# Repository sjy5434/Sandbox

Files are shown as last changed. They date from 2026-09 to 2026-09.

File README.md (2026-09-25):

# Koi Fish Joint Test Piece

A small OpenSCAD test print for an articulating koi fish: two tapered body
segments joined by a print-in-place ball-and-socket joint, with a separate
raised scale layer for dual-color printing on the AMS.

## Files

- `koi_joint_test.scad` — the parametric model.
- `export/joint_test_body.stl` — base body (both segments + joint), color 1.
- `export/joint_test_scales.stl` — raised scale layer, color 2.
- `export/koi_joint_test.3mf` — combined preview export only; confirmed
  single-object, see note below.

## Use the two STLs, not the 3MF

Confirmed in this environment: OpenSCAD 2021.01's built-in 3MF exporter
flattens the whole design into a **single mesh/object** (verified by
inspecting the exported `3D/3dmodel.model` XML — it contains exactly one
`<object>` element covering both the body and the scales). It does not
preserve them as separate objects the way Bambu Studio needs in order to
expose two independently paintable parts, so `koi_joint_test.3mf` is only
useful as a quick single-color preview, not for AMS slot assignment.

Use the two STL files instead — that's the reliable workflow:

1. In Bambu Studio, **Import** both `joint_test_body.stl` and
   `joint_test_scales.stl` into the same project.
2. They will already be aligned (both were exported from the same
   coordinate system in the .scad file — don't move one without the other).
3. Right-click each part → assign it to a different AMS filament slot
   (e.g. body → slot 1, scales → slot 2).
4. Group/arrange as needed, but keep their relative position fixed so the
   scale layer still sits flush on the body surface.

If you'd rather have a single file, Bambu Studio can merge the two STLs into
one project and re-export as a `.3mf` itself — that project-level 3MF *does*
preserve the two objects/paint assignments, unlike OpenSCAD's exporter.

## Print orientation

**Print it exactly as modeled — joint axis vertical (Z), no rotation in the
slicer.** The socket cavity opens upward by design:

- Segment B (bottom) tapers 18→14 mm and has the ball-cage/socket carved
  into its top.
- The ball (attached to segment A) sits inside that cage with a uniform
  `joint_clearance` (0.3 mm default) gap on all sides.
- Segment A (top) tapers 14→18 mm, connected to the ball by a short neck rod
  that passes up through a flared opening in the socket's top.

Because the opening faces up, the ball's equator and upper hemisphere print
as a series of closely-nested rings right next to the matching socket wall,
separated only by the clearance gap. That gap is small enough to bridge
layer-by-layer, so **no internal supports are needed inside the joint
cavity**. Do not lay the part on its side — that reintroduces a real
overhang on the ball and will force supports that fuse into the socket.

No supports are needed anywhere else on the part either (the tapered bodies
and scale bumps are all self-supporting/shallow-angle geometry). Standard
0.2 mm layer height should be fine; if your printer/filament tends to blob
on bridges, consider dropping to 0.16 mm around the joint region only.

## Build volume sanity check

With the default parameters:

- Total height ≈ 25 (segment B) + ~11.6 (joint/neck region) + 25 (segment A)
  ≈ **61.6 mm**
- Max diameter ≈ **18 mm** (the large end of each segment; the joint knuckle
  bulges to ~15.2 mm, still under the segment's max diameter)

That's a footprint on the order of 18 × 18 mm and ~62 mm tall — trivially
within the Bambu Lab A1 mini's 180 × 180 × 180 mm build volume, whether you
print it standing up (as recommended) or need to reorient for some other
reason.

## Judging `joint_clearance` after the test print

Print with the default `joint_clearance = 0.3` mm first, then adjust based
on what you see:

**Too tight (fused / won't move):**
- The joint doesn't rotate at all, or takes visible force and grinds/creaks.
- You see witness marks or torn strands where the ball and socket surfaces
  touched and welded together during printing.
- Twisting it further shows white stress marks or the neck rod flexing
  instead of the ball rotating.
- Fix: increase `joint_clearance` in 0.05–0.1 mm steps (try 0.35, then 0.4)
  and reprint.

**Too loose (sloppy articulation):**
- The ball rattles inside the socket or has noticeable play/wobble beyond
  just rotating.
- You can see daylight/gap around the ball when viewed from the side at the
  equator, well beyond a thin uniform line.
- The joint flops under the segment's own weight instead of holding a pose.
- Fix: decrease `joint_clearance` in 0.05 mm steps (try 0.25, then 0.2) and
  reprint. Very fine-detail printers/filaments (e.g. well-tuned PETG or ABS)
  can often go tighter than PLA before fusing.

**Good result:** the joint rotates smoothly with light, consistent
resistance in every direction, holds a pose against gravity, and shows no
fused/torn surface texture when you look inside the visible neck opening.

Other parameters worth revisiting once clearance is dialed in:
- `opening_extra` / `opening_flare` control how much the ball can swing
  before the neck rod hits the socket's opening wall — widen these if you
  want more range of motion once the base friction is right.
- `scale_size`, `scale_spacing_v`, `scale_spacing_a`, `scale_height` control
  the scale texture density/relief and can be tuned independently of the
  joint.

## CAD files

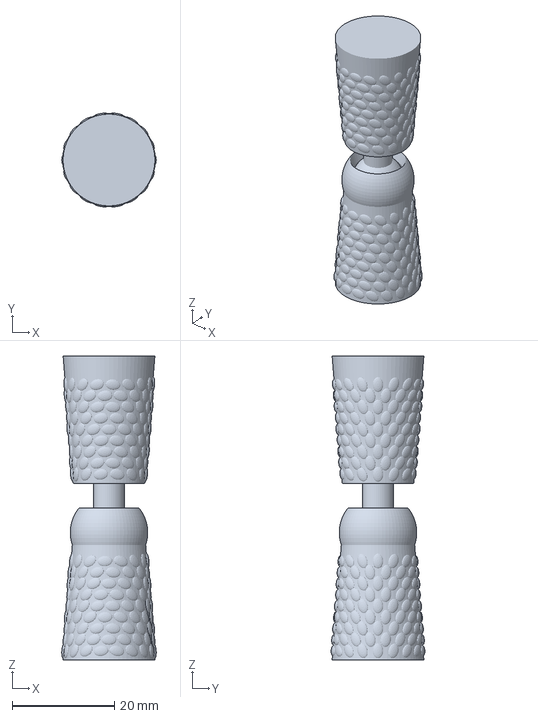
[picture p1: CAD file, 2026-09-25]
export/koi_joint_test.3mf
18.5 x 18.4 x 59.6 mm

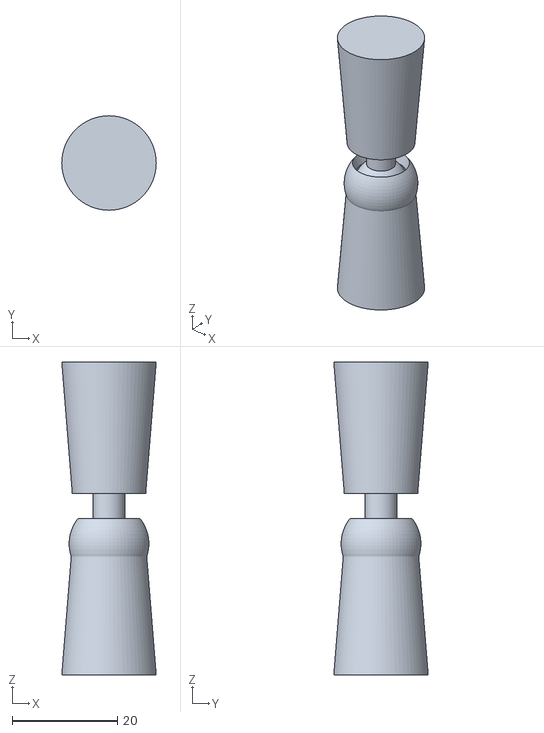
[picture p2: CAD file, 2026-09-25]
export/joint_test_body.stl
18.0 x 18.0 x 59.6

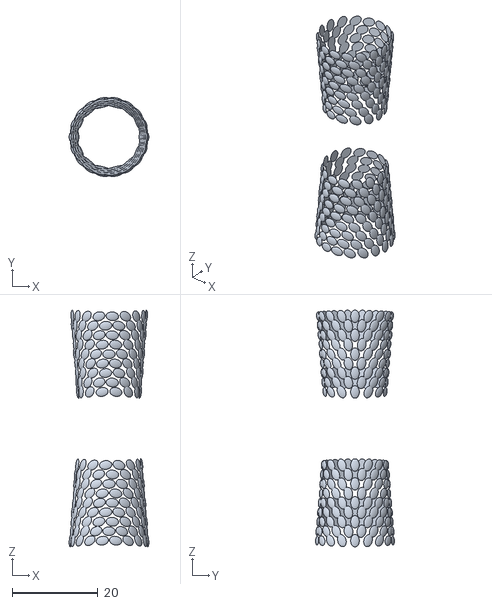
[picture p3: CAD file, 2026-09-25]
export/joint_test_scales.stl
18.5 x 18.4 x 55.1

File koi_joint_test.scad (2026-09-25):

// ============================================================================
// koi_joint_test.scad
//
// Small test piece for an articulating koi fish: two tapered body segments
// joined by a PRINT-IN-PLACE ball-and-socket joint, plus a separate raised
// scale layer for dual-color (AMS) printing.
//
// PRINT ORIENTATION (do not rotate before slicing):
//   The model is built with the joint axis along Z and the socket cavity
//   opening UPWARD (segment B at the bottom, its socket facing +Z; the ball
//   and segment A sit above it). Printing with this orientation as-is is
//   what lets the ball's equator/upper hemisphere print without support:
//   each layer of the ball is closely nested inside a matching ring of the
//   socket wall, separated only by `joint_clearance`, so the gap is bridged
//   layer-by-layer instead of needing an overhang support structure. Do NOT
//   lay the model on its side in the slicer, or the ball will need supports
//   that fuse into the socket cavity.
//
// Two independent top-level solids are emitted (never unioned together):
//   - base_body()   : the printable body (both tapered segments + joint)
//   - scales_layer(): raised scale bumps, sitting exactly on the body's
//                      outer surface, for assigning to a second AMS slot.
//
// Render/export selection is controlled by the `render_part` variable below,
// which can be overridden from the command line with -D, e.g.:
//   openscad -D 'render_part="body"'   -o joint_test_body.stl   koi_joint_test.scad
//   openscad -D 'render_part="scales"' -o joint_test_scales.stl koi_joint_test.scad
// ============================================================================

/* [Articulation - tune these after the first test print] */
joint_clearance = 0.3;   // gap (mm) between ball and socket surfaces
seg_length      = 25;    // length (mm) of each tapered body segment
diam_large      = 18;    // large-end diameter (mm) of each segment
diam_small      = 14;    // small-end (joint-side) diameter (mm) of each segment

/* [Joint geometry - secondary tunables] */
ball_d        = 11;    // ball diameter (mm)
neck_d        = 6;     // diameter (mm) of the rigid rod connecting segment A to the ball
opening_extra = 2.5;   // how much wider than the neck the socket's top opening starts (mm)
opening_flare = 4;     // extra widening (mm) of the opening toward the top, for range of motion
socket_wall   = 1.8;   // wall thickness (mm) of the socket housing around the ball cavity

/* [Scale texture - parametric] */
scale_size      = 3;     // scale footprint length along the body (mm)
scale_width     = 0.7;   // scale width as a fraction of scale_size
scale_height    = 0.4;   // how far scales sit proud of the base body surface (mm)
scale_spacing_v = 2.2;   // vertical spacing between scale rows (mm) - less than scale_size so rows overlap
scale_spacing_a = 3.0;   // approx. arc spacing between scales within a row (mm)

/* [Render control] */
render_part = "both"; // "both" | "body" | "scales"  (override with -D on the command line)

$fn = 64;

// ---------------------------------------------------------------------------
// Derived dimensions
// ---------------------------------------------------------------------------
ball_r    = ball_d / 2;
neck_r    = neck_d / 2;
opening_r = neck_r + joint_clearance + opening_extra / 2;
housing_r = ball_r + joint_clearance + socket_wall;

z_ball      = seg_length;              // height of the ball/socket center (top of segment B's taper)
neck_len    = housing_r + 2;           // neck rod length from ball center to above the housing dome
neck_top_z  = z_ball + neck_len;       // height where segment A's tapered body begins

// ---------------------------------------------------------------------------
// Generic helper: rotate children so their local +Z axis aligns with vector v
// ---------------------------------------------------------------------------
module align_to(v) {
    vn = v / norm(v);
    zaxis = [0, 0, 1];
    d = zaxis * vn;
    if (d > 0.999999) {
        children();
    } else if (d < -0.999999) {
        rotate([180, 0, 0]) children();
    } else {
        ax = cross(zaxis, vn);
        ang = acos(d);
        rotate(a = ang, v = ax) children();
    }
}

// ---------------------------------------------------------------------------
// BASE BODY: segment B (bottom) + socket housing + ball/neck + segment A (top)
// ---------------------------------------------------------------------------
module tapered_body(len, d1, d2) {
    cylinder(h = len, d1 = d1, d2 = d2, $fn = 64);
}

module base_body() {
    union() {
        // Segment B: tapered body with the socket housing carved into its top
        difference() {
            union() {
                tapered_body(seg_length, diam_large, diam_small);
                translate([0, 0, z_ball]) sphere(r = housing_r, $fn = 64);
            }
            // Ball clearance cavity (full sphere so the ball is caged, not just resting in a bowl)
            translate([0, 0, z_ball]) sphere(r = ball_r + joint_clearance, $fn = 64);
            // Upward-facing opening for the neck rod; flares outward near the top for swing range
            translate([0, 0, z_ball])
                cylinder(h = neck_len + 5, r1 = opening_r, r2 = opening_r + opening_flare, $fn = 48);
        }

        // Ball + neck, rigidly part of segment A, sitting inside B's cavity with clearance on all sides
        translate([0, 0, z_ball]) sphere(r = ball_r, $fn = 64);
        translate([0, 0, z_ball]) cylinder(h = neck_len, r = neck_r, $fn = 48);

        // Segment A: tapered body above the neck
        translate([0, 0, neck_top_z]) tapered_body(seg_length, diam_small, diam_large);
    }
}

// ---------------------------------------------------------------------------
// SCALE LAYER: separate solid, raised scale_height above the base body surface
// ---------------------------------------------------------------------------
module scale_bump() {
    // Half-ellipsoid ("half-moon") dome: flat base at z=0 sits exactly on the
    // body's tangent plane at each grid point, dome rises +scale_height above it.
    intersection() {
        scale([scale_size / 2, (scale_size * scale_width) / 2, scale_height])
            sphere(r = 1, $fn = 16);
        translate([-100, -100, 0]) cube([200, 200, 200]);
    }
}

// Places one scale on a cone of local slope m (dr/dz) at azimuth theta and height z_local,
// with the cone's local radius r_local at that height.
module place_bump(theta, z_local, r_local, m) {
    pos = [r_local * cos(theta), r_local * sin(theta), z_local];
    normal = [cos(theta), sin(theta), -m];
    translate(pos) align_to(normal) scale_bump();
}

// Generates a diagonal (staggered) grid of scales over a tapered segment of length `len`
// whose radius goes from r1 (z=0) to r2 (z=len).
module gen_scales(len, r1, r2) {
    m = (r2 - r1) / len;
    margin = scale_size * 0.6;
    usable = len - 2 * margin;
    num_rows = floor(usable / scale_spacing_v);
    for (row = [0 : num_rows - 1]) {
        z = margin + row * scale_spacing_v;
        r_local = r1 + m * z;
        circumference = 2 * PI * r_local;
        num_cols = max(6, floor(circumference / scale_spacing_a));
        theta_step = 360 / num_cols;
        offset = (row % 2 == 0) ? 0 : theta_step / 2;
        for (col = [0 : num_cols - 1]) {
            theta = col * theta_step + offset;
            place_bump(theta, z, r_local, m);
        }
    }
}

module scales_layer() {
    union() {
        // Scales on segment B (bottom, large->small going up)
        gen_scales(seg_length, diam_large / 2, diam_small / 2);
        // Scales on segment A (top, small->large going up) - joint knuckle left bare
        translate([0, 0, neck_top_z]) gen_scales(seg_length, diam_small / 2, diam_large / 2);
    }
}

// ---------------------------------------------------------------------------
// Output selection
// ---------------------------------------------------------------------------
if (render_part == "body") {
    base_body();
} else if (render_part == "scales") {
    scales_layer();
} else {
    base_body();
    color("Orange") scales_layer();
}

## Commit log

2026-09-25 Add koi joint test: print-in-place ball joint with dual-color scales
    Two tapered body segments (25mm, 18->14mm) joined by a captured
    ball-and-socket joint printed with the socket opening facing up so no
    internal supports are needed. joint_clearance, segment length, and
    diameter are top-level parameters for tuning after the first print.
    Scales are modeled as a separate solid raised ~0.4mm above the body
    surface in a diagonal, overlapping grid, so it can be assigned to a
    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
    [joint_test_body.stl, joint_test_scales.stl, koi_joint_test.scad]
2026-09-25 Confirm 3MF export is single-object; document STL workflow
    Inspected the exported 3MF's model XML directly: OpenSCAD 2021.01
    merges body and scales into one <object>, so it can't be used for
    per-part AMS color assignment. Updated the README accordingly and
    included the 3MF only as a single-color preview file.
    Claude-Session: https://claude.ai/code/session_01ACx5Fg6q9XEeF4PAps7tFd
    [koi_joint_test.3mf]
